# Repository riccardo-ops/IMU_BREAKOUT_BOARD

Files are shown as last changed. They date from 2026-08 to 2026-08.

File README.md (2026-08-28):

In this repo, a simple breakout board is made to include an IMU and a barometer.

IMU = LSM6DSV16XTR -> https://www.mouser.it/it/ProductDetail/STMicroelectronics/LSM6DSV16XTR?qs=MyNHzdoqoQLCWe%2FE3pkKcA%3D%3D
Barometer = MS5611-01BA03 -> https://www.te.com/commerce/DocumentDelivery/DDEController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

The idea is simple : create a breakout board with two common and low cost sensors that can easily be interfaced with FPGAs, Arduino, STM32, etc.

Some tips for this board : 
- Connectors : simple pin header, every Arduino starter pack has compatible cables.
- User LED : two user controlled LED are put inside this board
- Power on LED : there's an LED connected to the power section of every IC. 
  If something goes wrong with power connections, the LED is a simple, but yet effective way to debug
- TVS Diode : those connectors can easily have transient current peaks. Burn the ICs in not something I want, so this kind of protection is needed.
  Every TVS diode eats some voltage, so keep this in mind when you design your protection module!
- 4 Layer : this can be overkill, but to have a solid ground plane is always a good idea when you use sensible sensors like IMU and barometers.
  In this project the maximum frequency of communication is 5 MHz, so there is no danger for high frequency.

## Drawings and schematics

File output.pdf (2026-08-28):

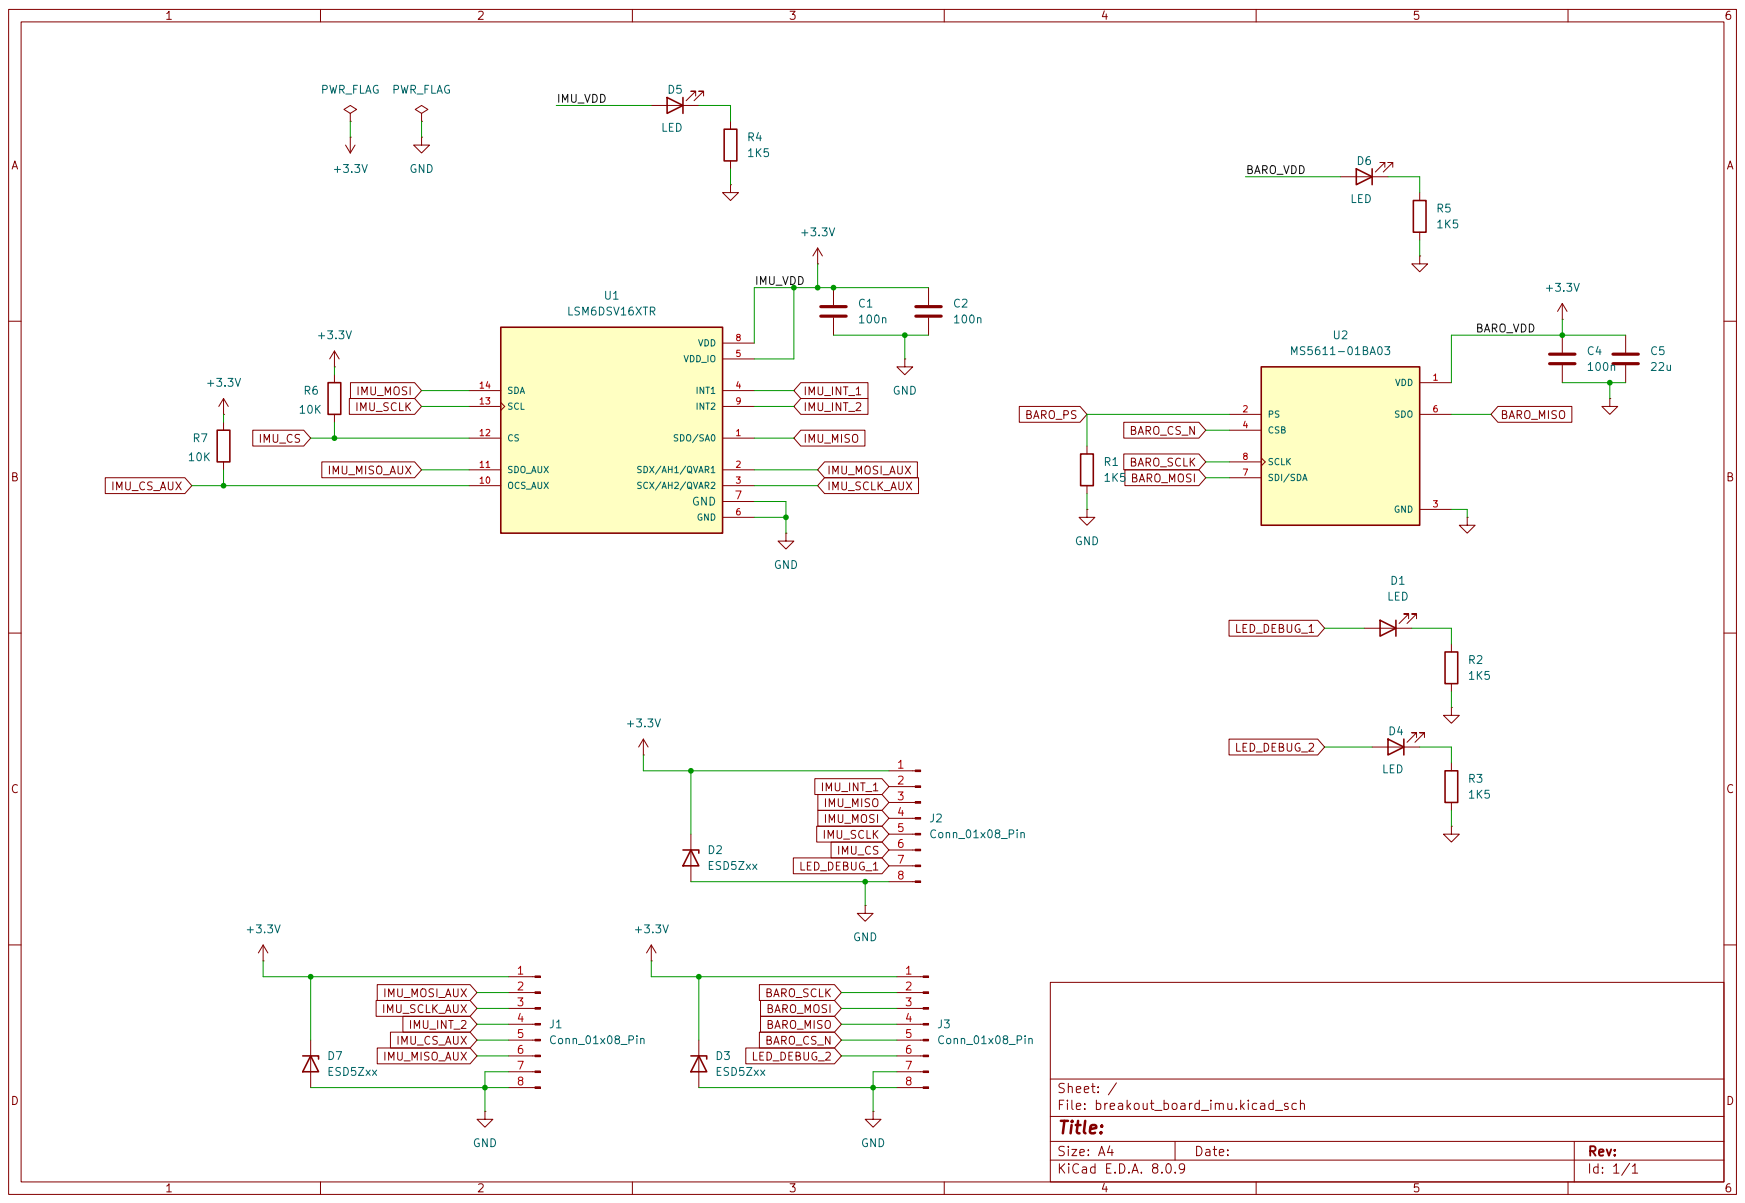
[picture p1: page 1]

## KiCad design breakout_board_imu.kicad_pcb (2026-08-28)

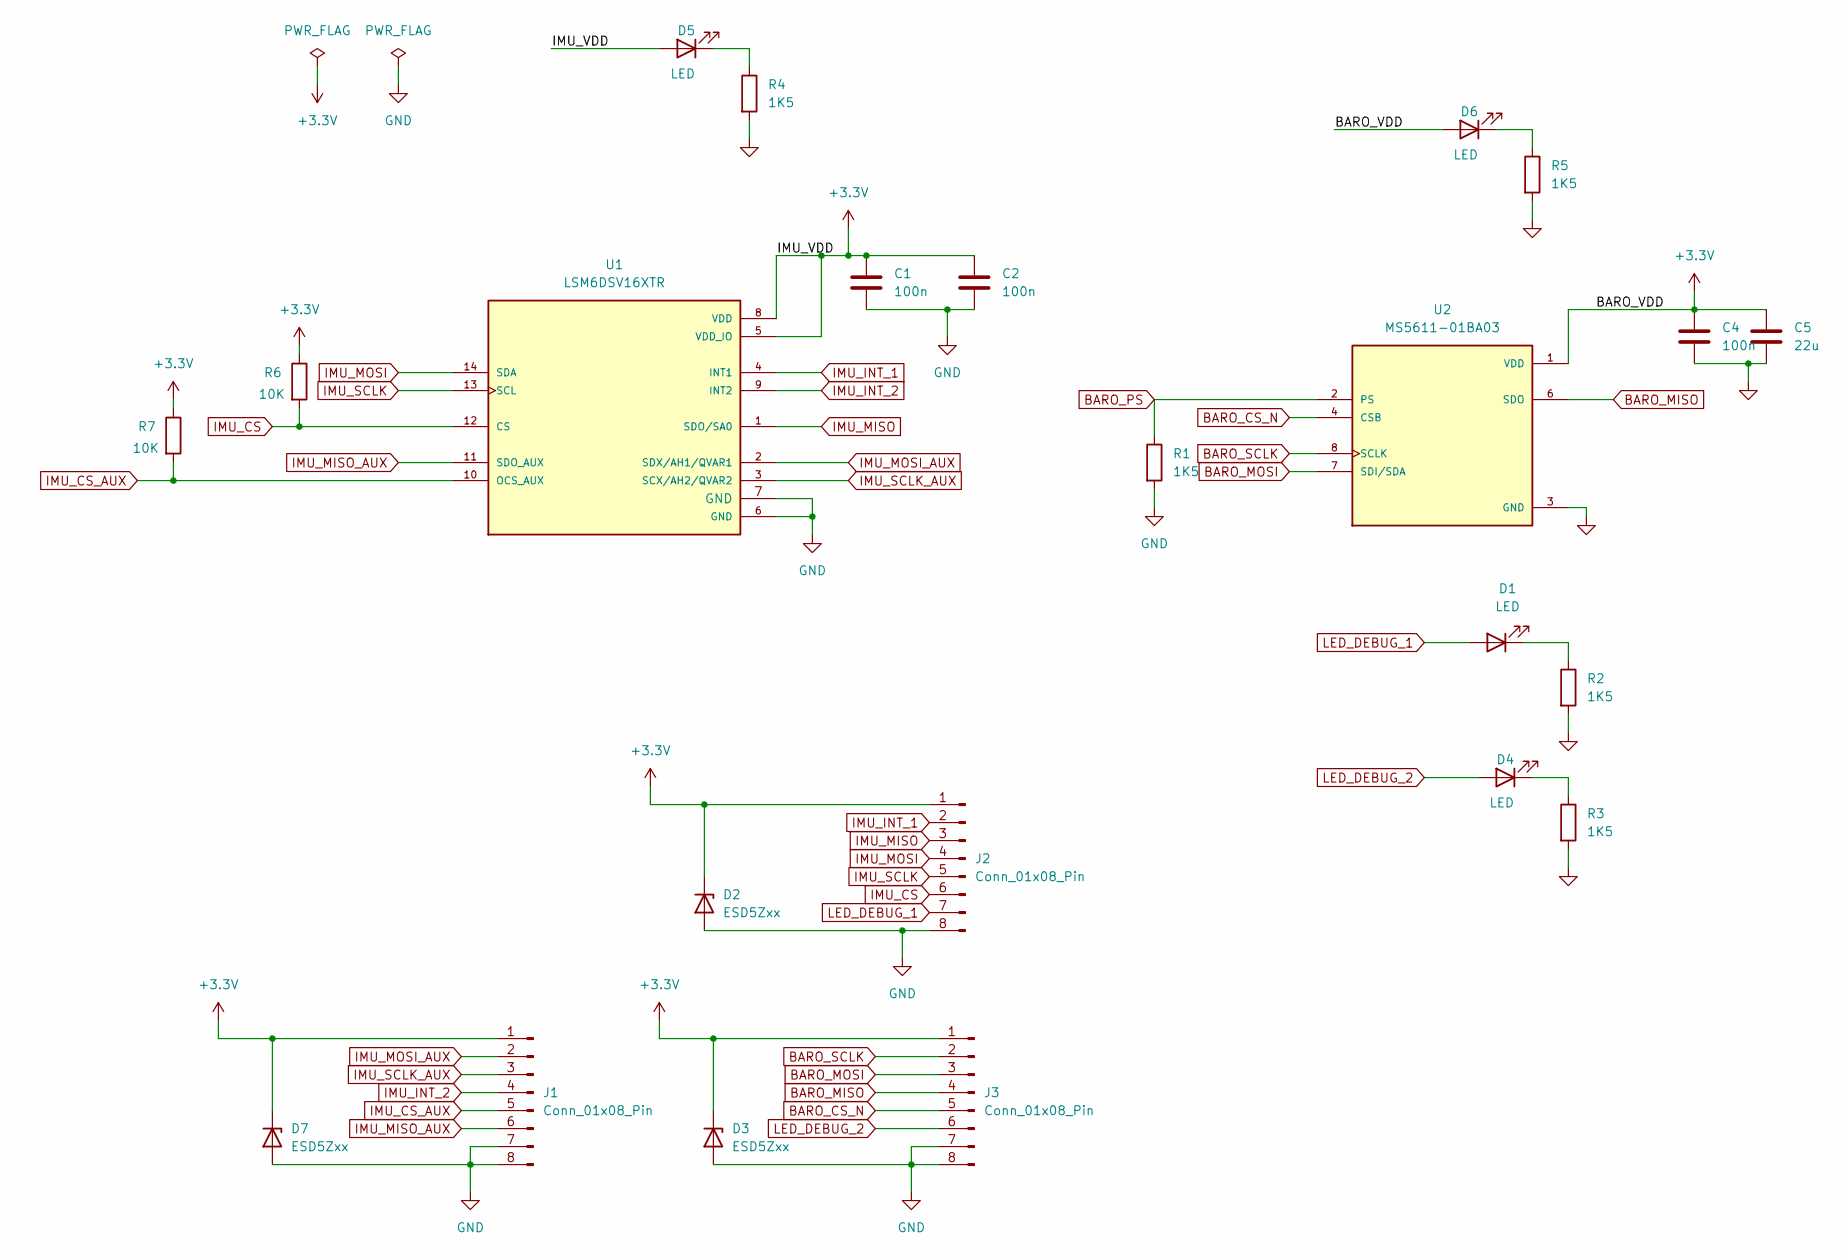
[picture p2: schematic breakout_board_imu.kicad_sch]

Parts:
C1, C2, C4: 100n; C_0402_1005Metric
C5: 22u; C_0805_2012Metric
D1, D4, D5, D6: LED; LED_0603_1608Metric
D2, D3, D7: ESD5Zxx; D_SOD-523
J1, J2, J3: Conn_01x08_Pin; PinHeader_1x08_P2.54mm_Vertical
R1, R2, R3, R4, R5: 1K5; R_0402_1005Metric
R6, R7: 10K; R_0805_2012Metric
U1: LSM6DSV16XTR; XDCR_LSM6DSV16XTR; PARTREV 4
U2: MS5611-01BA03; SON125P500X300X100-8N; PARTREV 06/2017

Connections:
+3.3V: C1.1, C2.1, C4.1, C5.1, D2.1 (K), D3.1 (K), D5.2 (A), D6.2 (A), D7.1 (K), J1.1, J2.1, J3.1, R6.1, R7.1, U1.5 (VDD_IO), U1.8 (VDD), U2.1 (VDD)
BARO_CS_N: J3.5, U2.4 (CSB), U2.5 (CSB)
BARO_MISO: J3.4, U2.6 (SDO)
BARO_MOSI: J3.3, U2.7 (SDI/SDA)
BARO_PS: R1.1, U2.2 (PS)
BARO_SCLK: J3.2, U2.8 (SCLK)
GND: C1.2, C2.2, C4.2, C5.2, D2.2 (A), D3.2 (A), D7.2 (A), J1.7, J1.8, J2.8, J3.7, J3.8, R1.2, R2.2, R3.2, R4.2, R5.2, U1.6 (GND), U1.7 (GND), U2.3 (GND)
IMU_CS: J2.6, R6.2, U1.12 (CS)
IMU_CS_AUX: J1.5, R7.2, U1.10 (OCS_AUX)
IMU_INT_1: J2.2, U1.4 (INT1)
IMU_INT_2: J1.4, U1.9 (INT2)
IMU_MISO: J2.3, U1.1 (SDO/SA0)
IMU_MISO_AUX: J1.6, U1.11 (SDO_AUX)
IMU_MOSI: J2.4, U1.14 (SDA)
IMU_MOSI_AUX: J1.2, U1.2 (SDX/AH1/QVAR1)
IMU_SCLK: J2.5, U1.13 (SCL)
IMU_SCLK_AUX: J1.3, U1.3 (SCX/AH2/QVAR2)
LED_DEBUG_1: D1.2 (A), J2.7
LED_DEBUG_2: D4.2 (A), J3.6
unnamed: D1.1 (K), R2.1
unnamed: D4.1 (K), R3.1
unnamed: D5.1 (K), R4.1
unnamed: D6.1 (K), R5.1

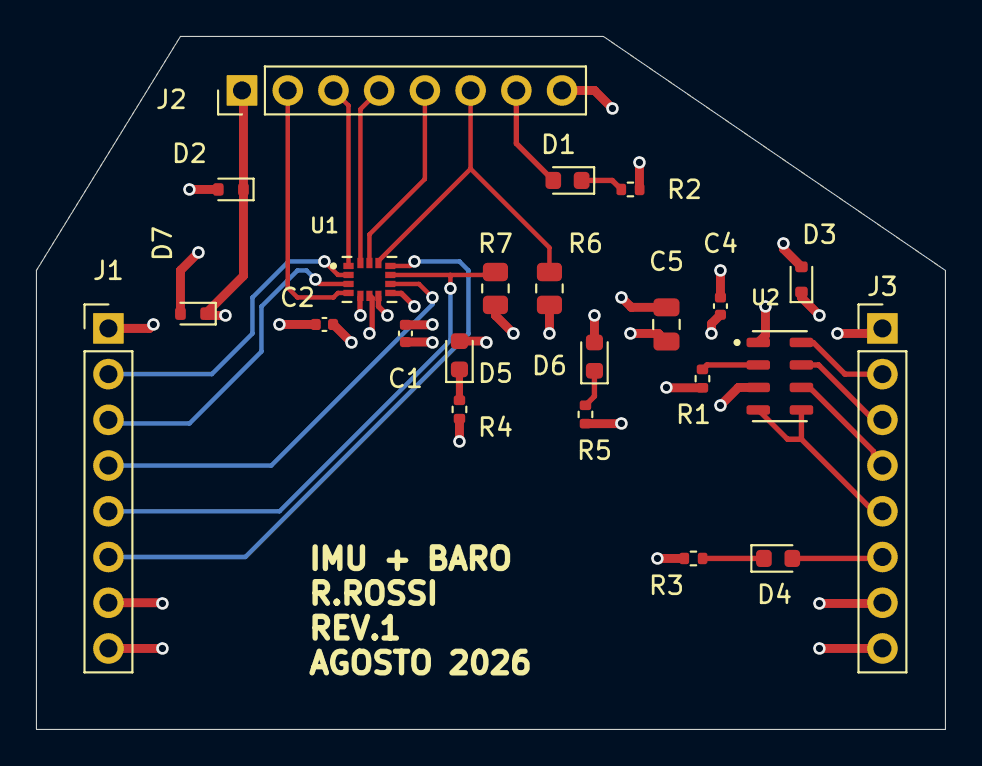
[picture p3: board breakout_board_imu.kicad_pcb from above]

Board: 4 copper layers, 50.5 x 38.5 mm, 23 parts (0 on the bottom side), 23 nets.

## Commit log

2026-08-28 First commit, Rev 0
    [bom-jlcpcb-template.csv, bom.csv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]
2026-08-28 Aggiunto .gitignore, rimossi file rigenerabili dal tracking
    [bom-jlcpcb-template.csv, bom.csv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]
2026-08-28 Added pdf of the schematic
2026-08-28 Add README
    Added a detailed description of the breakout board including components, tips, and design considerations.
